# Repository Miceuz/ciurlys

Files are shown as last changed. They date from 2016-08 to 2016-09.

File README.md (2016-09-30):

# Čiurlys (Apus Apus)

Electronics to support the light art installation Apus Apus by Justė Brukštutė / Jonas Liugaila / Rūta Ivaškevičiūtė / Albertas Mickėnas.

The installation consists of several acrylic tubes that are shaped to different frames of an animation 
depicting a flight of a bird.

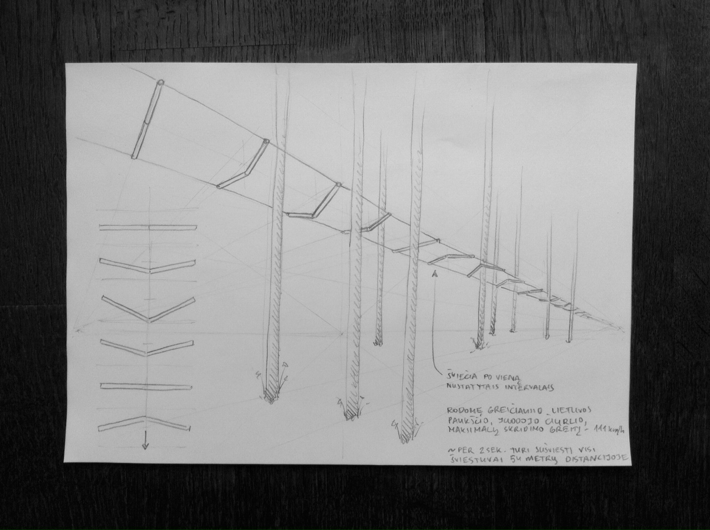
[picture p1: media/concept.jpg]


Acrylic tubes have a LED strip and controll electronics installed in them. Each tube has a small microcontroller that 
implements a simple protocol that allows to daisy-chain the segmens.

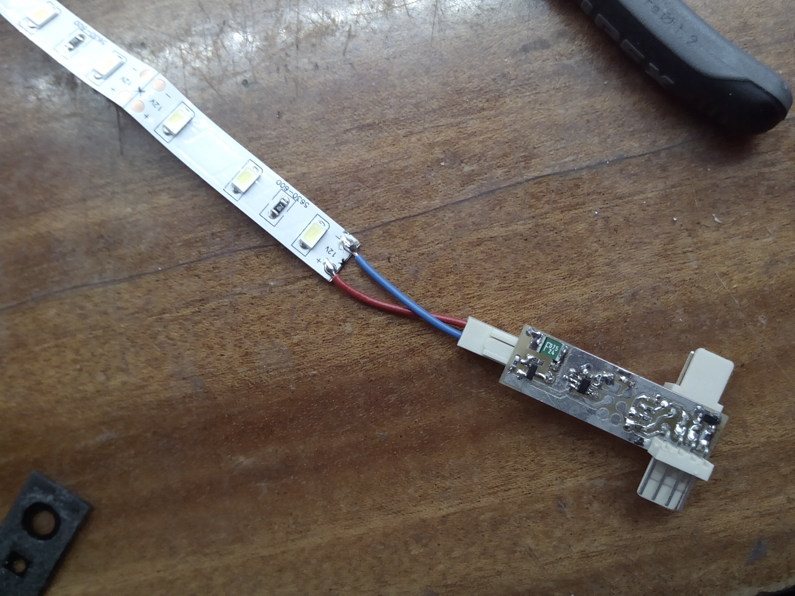
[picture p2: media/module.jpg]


The main callenges were to fight the inductivity of the cable and dampen the ringing on power lines - zeners were enough 
to avoid dangerously high and negative spikes. The output transistor has enough of umph to survive a dead short while 
polyfuse catches up. Input protection transils were not implemented to keep the cost low, I got to rely on the protection diodes
inside the attiny.



For now the firmware is waiting for pulse on the input pin then outputs pulses of the same length on the output pin. A
digital one-wire protocol similar to the one used in ws2812 or proprietary Maxim 1-Wire® protocol is envisioned for the future.

```c
	while(1) {
		while(isInputHigh()) {
			//wait
		}

		startInputPulseTimer();
		while(isInputLow() && !inputTimeout) {
			if(isNotaGlitch()) {
				on(LED);
			}
			//wait
		}
		stopInputPulseTimer();
		off(LED);

		if(inputTimeout) {
			while(isInputLow()) {
				//wait
			}
		} else {
			if(isNotaGlitch()) {
				off(OUTPUT);
				startOutputPulseTimer();
				while(!outputPulseDone) {
					//wait
				}
				stopOutputPulseTimer();
				on(OUTPUT);
			}
		}
	}
```

A video of the installation being set up:

Apus Apus - setup (http://www.youtube.com/watch?v=SOXjC1DidxA?rel=0)

A video of the installation running at night:

IMAGE ALT TEXT HERE (http://www.youtube.com/watch?v=rREeh75hglU?rel=0)

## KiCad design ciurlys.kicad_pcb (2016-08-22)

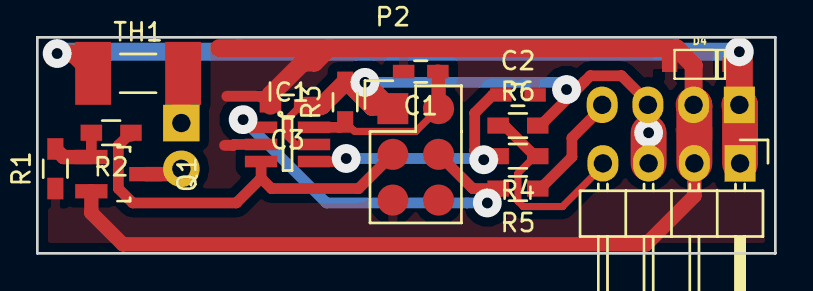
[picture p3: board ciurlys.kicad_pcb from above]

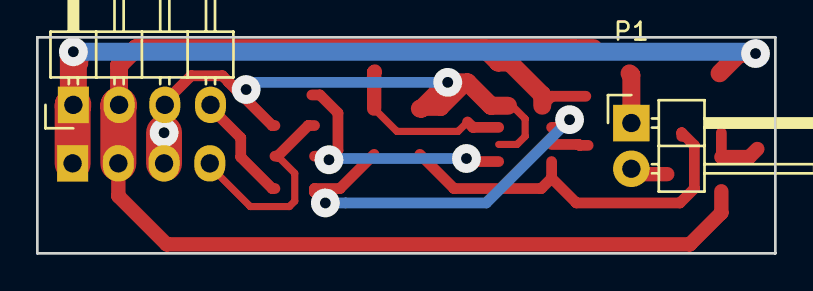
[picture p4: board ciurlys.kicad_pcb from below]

Board: 2 copper layers, 41.0 x 12.0 mm, 17 parts (2 on the bottom side), 12 nets.

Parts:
C1, C2, C3: C; C_0603_HandSoldering
D4: TRANSIL; sod123
IC1: ATTINY9-TS; SOT-23-6
P1: CONN_01X02; Pin_Header_Angled_1x02
P2: TPI; Pin_Header_Straight_2x03
P3: OUTPUT; Pin_Header_Angled_1x04
P4: INPUT; Pin_Header_Angled_1x04
Q1: Q_NMOS_GSD; SOT-23_Handsoldering
R1, R3, R6: 10k; R_0603_HandSoldering
R2: 330; R_0603_HandSoldering
R4, R5: 1k; R_0603_HandSoldering
TH1: THERMISTOR; R_1206_HandSoldering

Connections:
GND: C1.2, C2.2, C3.2, D4.1, IC1.2, P2.5, P3.2, P4.2, Q1.2, R1.1
unnamed: C1.1, IC1.6, P2.2, R3.1
unnamed: C2.1, IC1.4, R4.2
unnamed: P4.4, R4.1, R6.1
unnamed: P3.4, R5.1
unnamed: IC1.1, P2.4, R5.2
unnamed: IC1.3, P2.3, R2.1
unnamed: P1.1, TH1.2
unnamed: P1.2, Q1.3
unnamed: Q1.1, R1.2, R2.2
VCC: C3.1, IC1.5, P2.1, P3.3, P4.3, R3.2, R6.2
VDD: D4.2, P3.1, P4.1, TH1.1

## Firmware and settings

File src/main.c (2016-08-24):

#include <inttypes.h>
#include <avr/io.h>
#include <avr/interrupt.h>
#include <util/delay.h>

#define OUTPUT PB0
#define LED PB1
#define INPUT PB2

inline static void on(uint8_t pin) {
	PORTB |= _BV(pin);	
}

inline static void off(uint8_t pin) {
	PORTB &= ~_BV(pin);
}

volatile uint8_t inputTimeout, outputPulseDone;
volatile uint16_t pulseLength;

inline static void startInputPulseTimer() {
	inputTimeout = 0;
	TCCR0A = 0;
	TCNT0 = 0;
	TIMSK0 = _BV(TOIE0);
	TCCR0B = _BV(CS00) | _BV(CS01);
}

inline static void stopInputPulseTimer() {
	pulseLength = TCNT0;
	TCCR0B = 0;
}

inline static void startOutputPulseTimer() {
	outputPulseDone = 0;
	TCCR0A = 0;
	TIFR0 |= _BV(OCF0A);
	TIMSK0 = _BV(TOIE0) | _BV(OCIE0A);
	OCR0A = pulseLength;
	TCNT0 = 0;
	TCCR0B = _BV(CS00) | _BV(CS01);// | _BV(WGM02); 
}

inline static stopOutputPulseTimer() {
	TCCR0B = 0;
}

inline static uint8_t isNotaGlitch() {
	return TCNT0 > 15;
}

ISR(TIM0_OVF_vect){
	inputTimeout = 1;
	outputPulseDone = 1;
	TCCR0B = 0;
}

ISR(TIM0_COMPA_vect) {
	outputPulseDone = 1;
}

inline static uint8_t isInputHigh() {
	return (PINB & _BV(INPUT));
}

inline static uint8_t isInputLow() {
	return !(PINB & _BV(INPUT));
}

void main(void) {

	DDRB |= _BV(LED) | _BV(OUTPUT);
	on(OUTPUT);
	_delay_ms(1);

	sei();

	while(1) {
		while(isInputHigh()) {
			//wait
		}

		startInputPulseTimer();
		while(isInputLow() && !inputTimeout) {
			if(isNotaGlitch()) {
				on(LED);
			}
			//wait
		}
		stopInputPulseTimer();
		off(LED);

		if(inputTimeout) {
			while(isInputLow()) {
				//wait
			}
		} else {
			if(isNotaGlitch()) {
				off(OUTPUT);
				startOutputPulseTimer();
				while(!outputPulseDone) {
					//wait
				}
				stopOutputPulseTimer();
				on(OUTPUT);
			}
		}
	}
}

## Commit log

2016-08-22 Initial commit. Boards are made, MCU can be programmed
    [garnys.kicad_pcb, garnys.sch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]
2016-09-05 Rename, add some videos
    [ciurlys.kicad_pcb, ciurlys.sch, garnys.sch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]
2016-09-05 Make schematics nicer, add zeners on vdd and vcc
    [ciurlys.sch]
2016-09-05 Add partlist, schematics svg
    [partlist.tsv]
